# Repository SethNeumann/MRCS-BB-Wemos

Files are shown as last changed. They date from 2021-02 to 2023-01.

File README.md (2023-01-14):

# REPO NAME: MRCS-BB-Wemos

## License: Creative Commons Attribution-NonCommercial-ShareAlike

This board contains a Wemos D1 processor, 1A regulator, level shifters and an MCP23017 to provide a rougth equivalent to a BB-Leo.

The Wemos D1 has considerably more code space than a ProMini/Leonardo
and could eventually support a "local fall back" mode when no CMRINet
is present and may support other protocols over WiFi.  It will use
John Plochers forthcoming cpNode sketch.

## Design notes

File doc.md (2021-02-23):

This board contains a Wemos D1 processor, 1A regulator, level shifters and an MCP23017 to provide a rougth equivalent to a BB-Leo.
This board has considerably more code space and will eventually support a "local fall back" mode when no CMRINet is present and may
support other protocols over WiFi.  It will use John Plochers forthcoming cpNode sketch.

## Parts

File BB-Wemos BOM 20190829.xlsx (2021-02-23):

Quantity | Part | Value | Device | Package | Description | MF | MPN | Vendor | Part | Unit | need
1 | C1 | 220uF | CAP-POLPTH-5MM | E5-10,5 |  | Kemet | ESH227M025AH1AA | Digikey | 399-6570-ND | 0.23 | 0
1 | C2 | 1.0uF | CAPPTH1 | C050-024X044 |  | TDK | FG18X5R1H105KRT00 | Digikey | 445-175540-ND | 0.14 | 5
1 | C3 | 10uF | CAPPTH1 | C050-024X044 |  | TDK | FG28X5R1E106MRT06 (https://www.mouser.com/ProductDetail/TDK/FG28X5R1E106MRT06) | Digikey | 445-181284-1-ND | 0.26 | 5
1 | SOC1` | 28 pin | DIP Socket | 28 pin 2 row 2.54mm pitch 7.62mm row spacing machined DIP socket |  | Mill Max | 110-47-328-41-001000 | Digikey | ED3050-5-ND | 0.22 | 0
1 | J1 |  | CONNECTOR-DC-POWER-RA | DCJ0202 | DC POWER JACK | Kobiconn | 163-179PH-EX | Banggood |  | 0.10 | 0
1 | LS2 |  | I2C-LEVELSHIFTER | MODULE | https://www.ebay.com/itm/10-x-Logic-Level-Shifter-Converter-Bi-Directional-5V-3-3V-DC-Module-for-Arduino/202624346925 | eBay | Various, 10x pcs |  |  | 0.65 | 0
1 | VR5.0 | 5v | VREG-PTH-FLAT-5 | TO-220 | Voltage Regulator | ON Semi | SCD7805BTG (https://www.mouser.com/ProductDetail/ON-Semiconductor/SCD7805BTG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) | Digikey | SCD7805BTGOS-ND | 0.30 | 5
1 | PCB |  |  |  | BB (cpNode) Wemos
2 | HDR 1,2 | 8 pos female | 8 position female header | 1x8 SIP
1 | HDR 3 | 6 pos male | 6 pos male | 1x6 SIP | for BB-Leo Footprint
1 | HDR4 | 16 Pos male | 16 Pos male | 1x16 SIP | for BB-Leo Footprint
1 | HDR 5 | 2x8 female | 2x8 female | 2x8 0.100 | for BB-Leo Footprint
 |  |  | Wemos-D |  | Wemos D
 |  |  |  |  |  |  |  |  |  | 7.83

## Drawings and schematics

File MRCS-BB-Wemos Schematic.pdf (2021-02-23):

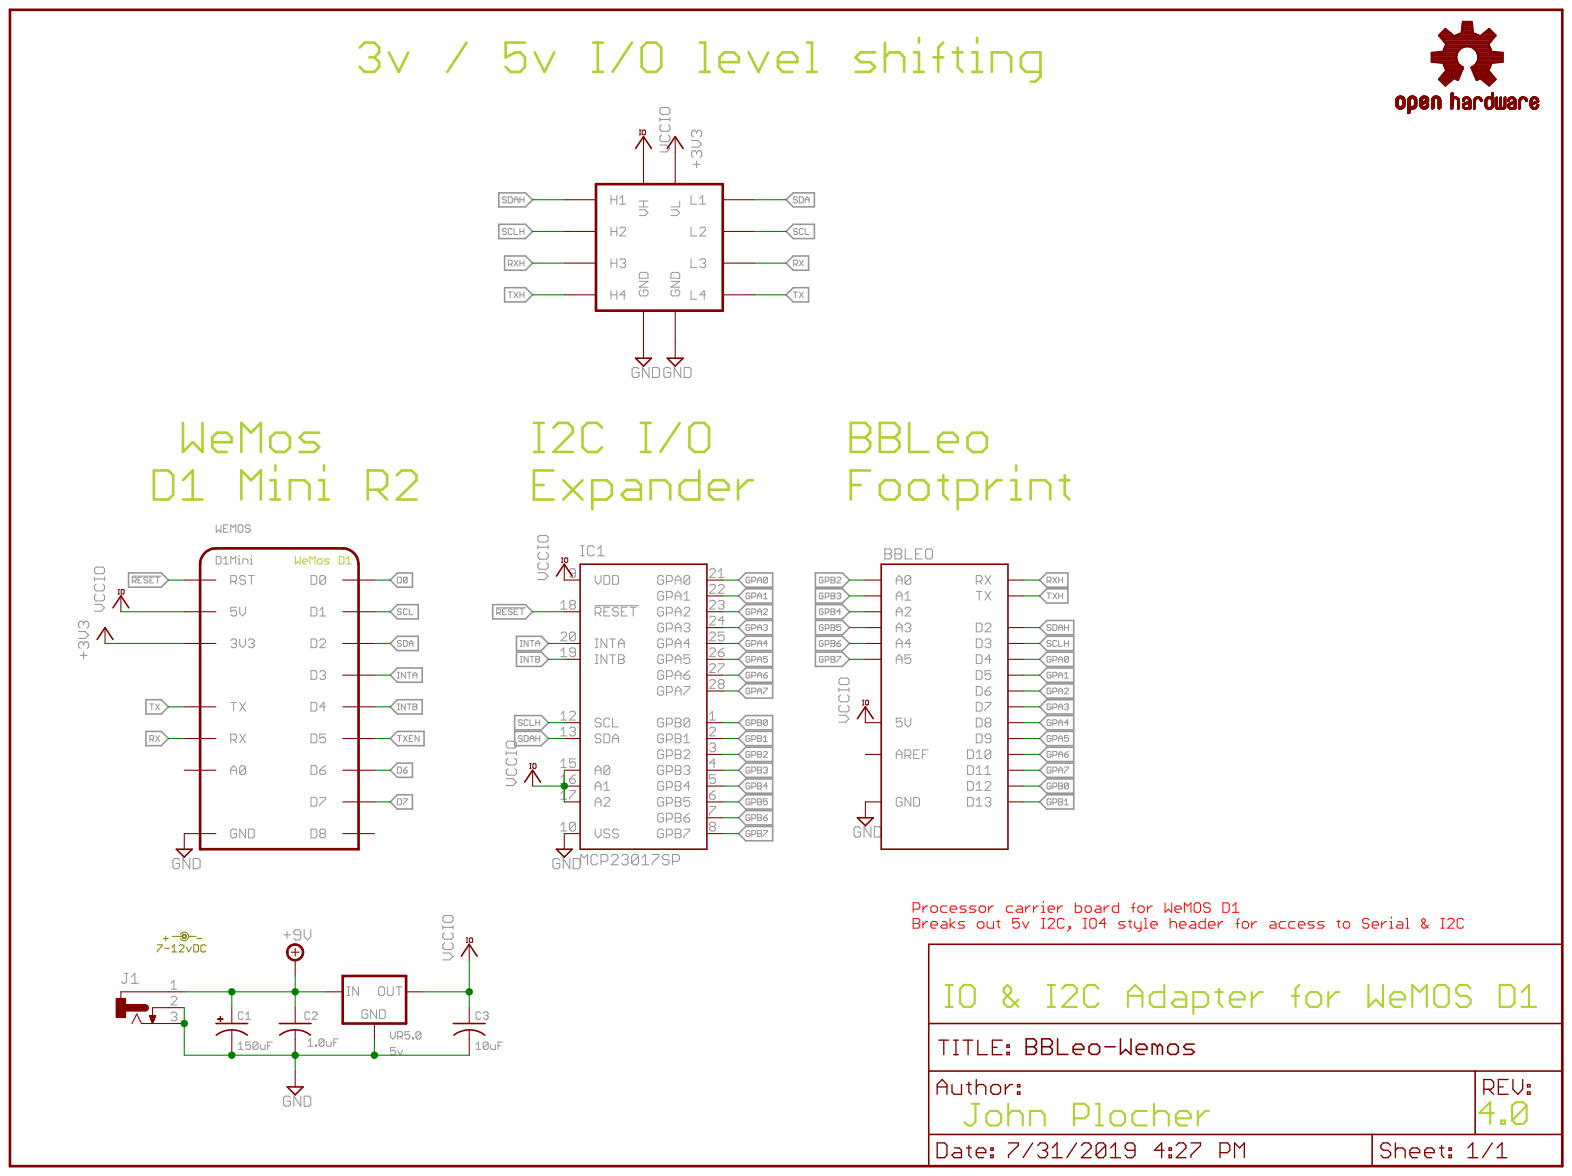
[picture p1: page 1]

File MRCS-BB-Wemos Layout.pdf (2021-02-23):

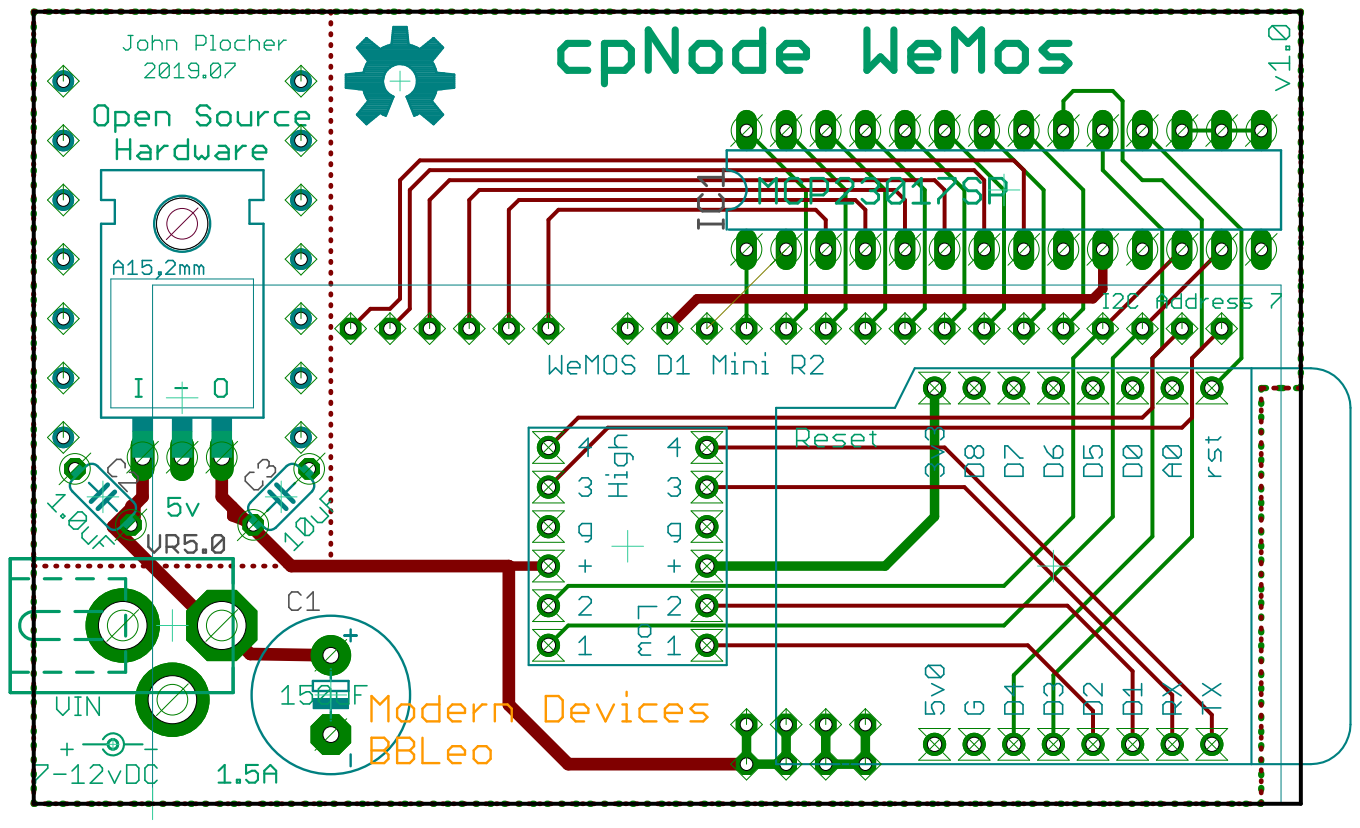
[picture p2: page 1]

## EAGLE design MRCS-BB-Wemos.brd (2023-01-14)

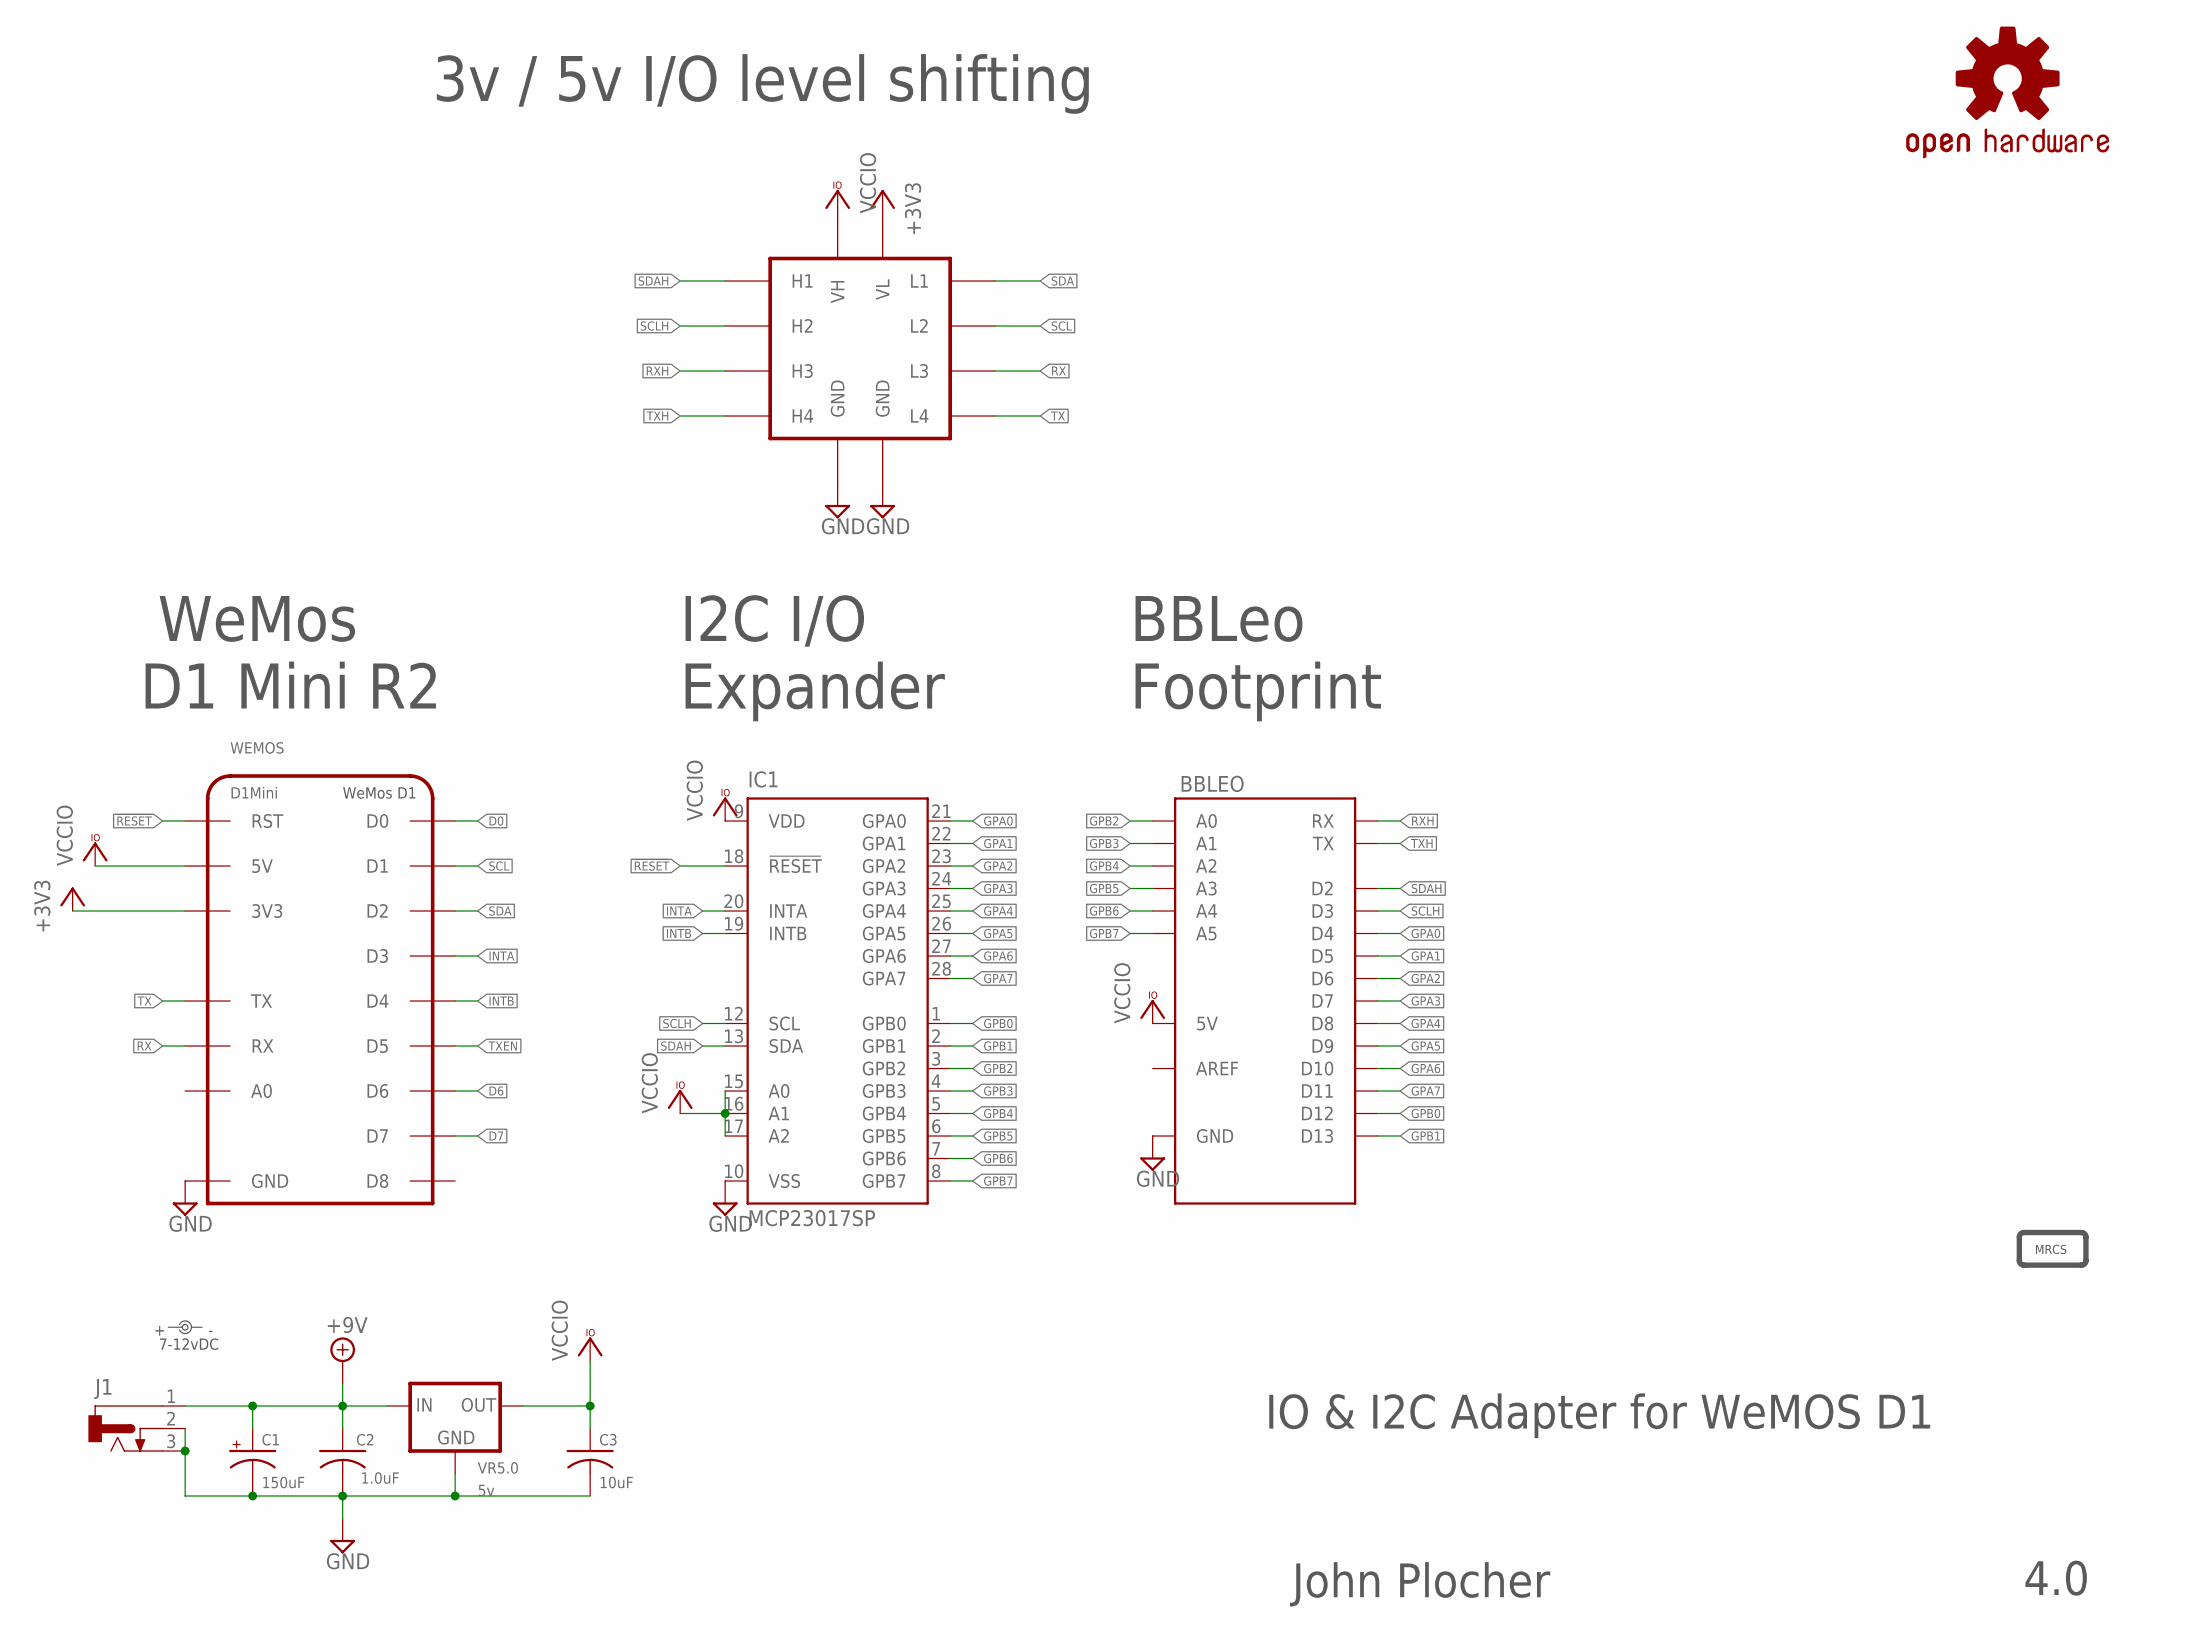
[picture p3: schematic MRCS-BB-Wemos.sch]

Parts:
BBLEO: ARDUINO-BBLEO
C1: 150uF; E5-10.5
C2: 1.0uF; C050-024X044
C3: 10uF; C050-024X044
IC1: MCP23017SP; DIL28-3
J1: CONNECTOR-DC-POWER-RA; DCJ0202
LABEL1: 7-12vDC; PWR_LABEL
LS2: I2C-LEVELSHIFTER; MODULE
OSHW1: DOC-OSHW-LOGO-L; OSHW-LOGO-L
U$1: DOC-MRCS-LOGOTOP; MRCS-LOGO
VR5.0: 5v; TO-220-RA
WEMOS: D1Mini; WEMOS-D1

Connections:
!RESET: IC1.18 (!RESET), WEMOS.RST
+3V3: LS2.LV (VL), WEMOS.3V3
+9V: C1.+, C2.1, J1.1, VR5.0.IN
D0: WEMOS.D0
D6: WEMOS.D6
D7: WEMOS.D7
GND: BBLEO.GND@0 (GND), BBLEO.GND@1 (GND), BBLEO.GND@2 (GND), BBLEO.GND@3 (GND), BBLEO.GND@4 (GND), C1.-, C2.2, C3.2, IC1.10 (VSS), J1.2, J1.3, LS2.GND@0 (GND), LS2.GND@1 (GND), VR5.0.GND, WEMOS.GND
GPA0: BBLEO.D4, IC1.21 (GPA0)
GPA1: BBLEO.D5, IC1.22 (GPA1)
GPA2: BBLEO.D6, IC1.23 (GPA2)
GPA3: BBLEO.D7, IC1.24 (GPA3)
GPA4: BBLEO.D8, IC1.25 (GPA4)
GPA5: BBLEO.D9, IC1.26 (GPA5)
GPA6: BBLEO.D10, IC1.27 (GPA6)
GPA7: BBLEO.D11, IC1.28 (GPA7)
GPB0: BBLEO.D12, IC1.1 (GPB0)
GPB1: BBLEO.D13, IC1.2 (GPB1)
GPB2: BBLEO.A0, IC1.3 (GPB2)
GPB3: BBLEO.A1, IC1.4 (GPB3)
GPB4: BBLEO.A2, IC1.5 (GPB4)
GPB5: BBLEO.A3, IC1.6 (GPB5)
GPB6: BBLEO.A4, IC1.7 (GPB6)
GPB7: BBLEO.A5, IC1.8 (GPB7)
INTA: IC1.20 (INTA), WEMOS.D3
INTB: IC1.19 (INTB), WEMOS.D4
RX: LS2.L3, WEMOS.RX
RXH: BBLEO.RX, LS2.H3
SCL: LS2.L2, WEMOS.D1
SCLH: BBLEO.SCL (D3), IC1.12 (SCL), LS2.H2
SDA: LS2.L1, WEMOS.D2
SDAH: BBLEO.SDA (D2), IC1.13 (SDA), LS2.H1
TX: LS2.L4, WEMOS.TX
TXEN: WEMOS.D5
TXH: BBLEO.TX, LS2.H4
VCCIO: BBLEO.+5V@1 (5V), BBLEO.+5V@2 (5V), BBLEO.+5V@3 (5V), BBLEO.+5V@4 (5V), C3.1, IC1.9 (VDD), IC1.15 (A0), IC1.16 (A1), IC1.17 (A2), LS2.HV (VH), VR5.0.OUT, WEMOS.5V

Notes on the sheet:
IO & I2C Adapter for WeMOS D1
John Plocher
4.0
WeMos D1 Mini R2
3v / 5v I/O level shifting
I2C I/O Expander
BBLeo Footprint

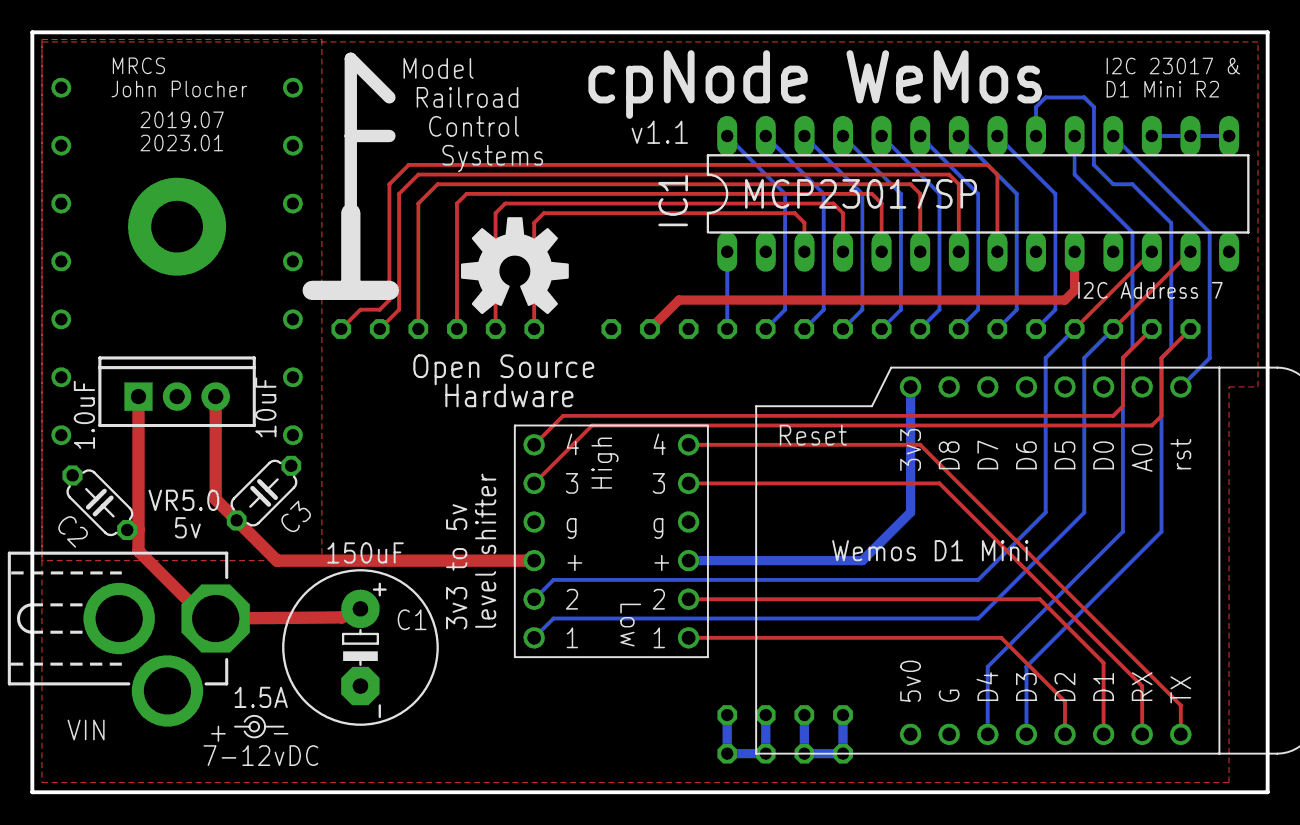
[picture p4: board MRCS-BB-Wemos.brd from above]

Board: 2 copper layers, 81.3 x 50.0 mm, 12 parts (0 on the bottom side), 31 nets.

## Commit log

2021-02-23 moved BB-Wemos from EAGLE directory
    we made a short run of these, which Dennis Drumheller bought.
    [BB-Wemos BOM 20190829.xlsx, EagleTemplate-new.brd, MRCS-BB-Wemos.brd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]
2023-01-14 replace / update components with newer ones in SPCoast library clean up silk screen, add MRCS
    [MRCS-BB-Wemos.brd, MRCS-BB-Wemos.sch]
2023-01-14 replace VR with RA version & mounting hole to W/A an eagle bug Add MRCS to sch
    [MRCS-BB-Wemos.brd, MRCS-BB-Wemos.sch]

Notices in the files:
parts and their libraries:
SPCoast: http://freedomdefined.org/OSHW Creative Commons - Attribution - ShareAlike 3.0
